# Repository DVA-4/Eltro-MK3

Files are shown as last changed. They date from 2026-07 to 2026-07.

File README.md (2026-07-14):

# Eltro MK3

A Eurorack effects module: a digital emulation of the **Eltro Tempophon** —
the rotating-head tape pitch/time changer famously used to create HAL 9000's
voice in *2001*.

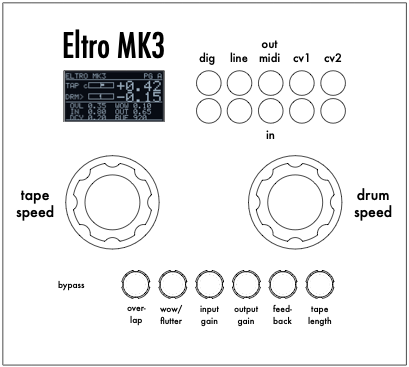
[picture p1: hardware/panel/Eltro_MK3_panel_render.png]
Eltro MK3 panel

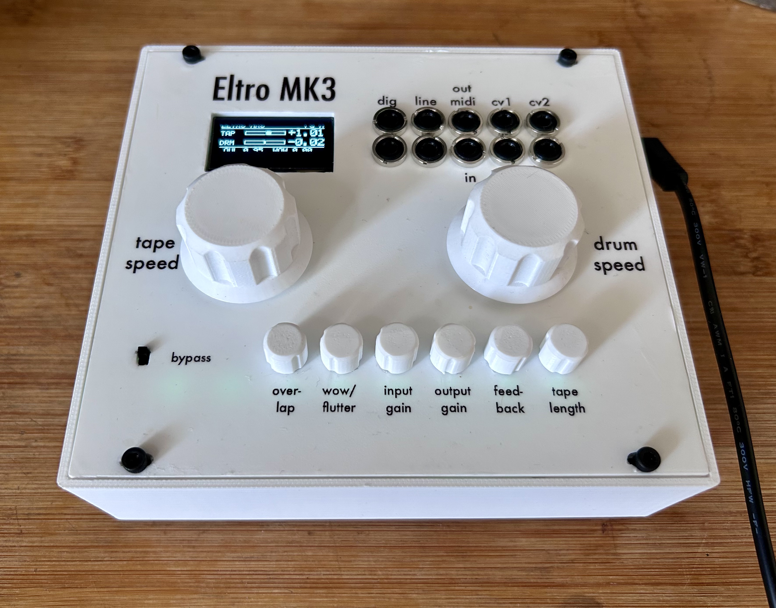
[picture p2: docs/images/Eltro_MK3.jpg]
Eltro MK3 overview

(https://www.youtube.com/watch?v=IvSktSFwxQE)

Live audio in → a buffered "tape" scanned by four virtual read heads → audio
out, with **time and pitch decoupled into two independent axes** (tape and
drum) — the same trick the real machine used, modelled directly rather than
approximated with a generic granular time-stretch.

Built on the **AMYboard** (ESP32-S3) using the **AMY** synth library, with an
M5Stack 8Angle for control, an SH1106 OLED for display, CV inputs, and MIDI
RX/TX.

## Features
- Two-axis DSP: progression (time) and pitch as independent parameters
- Silence-at-freeze, reverse-scan, and speed/pitch decoupling — all modelled
  from the physical machine's behaviour, not faked
- 2× CV inputs (tape, drum)
- MIDI RX (CC control with per-knob pickup/catch takeover) and MIDI TX
  (knob movement → CC out)
- OLED UI with two parameter pages, persisted settings
- 3D-printed Eurorack panel and matching knobs

## Status
Working, hardware-confirmed final prototype. See `CHANGELOG.md` for version
history.

## Repository structure
```
firmware/       Arduino sketch (eltro_mk3_v12) + font table
hardware/       3D-printable panel, knob, and case STLs, panel design source
docs/           Build guide, BOM, user manual, technical notes
```

The skiff case is a remix of a third-party CC BY 4.0 design — see
`hardware/CASE_NOTE.md` for attribution.

## Getting started
- **Building one yourself:** start with `docs/BUILD_GUIDE.md` and `docs/BOM.md`
- **How it works technically:** `docs/TECHNICAL_NOTES.md`
- **How to use it once it's built:** `docs/manual/Eltro_MK3_Manual.pdf`

## Dependencies
- [AMY](https://github.com/shorepine/amy) synth library (MIT licensed) —
  not bundled here, install separately

## License
- Firmware (`firmware/`): MIT — see `LICENSE-CODE.md`
- Hardware designs and documentation (`hardware/`, `docs/`): CC BY-SA 4.0 —
  see `LICENSE-HARDWARE.md`

## Credits
Built by Fabian Rieber 2026 (DVA-4). Digital emulation of the Eltro Tempophon concept;
"itty-bitty bits, cross-faded" description of the segment-crossfade
mechanism is Wendy Carlos's, describing the original hardware.

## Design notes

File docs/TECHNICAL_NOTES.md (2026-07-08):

# Eltro MK3 — Technical Notes

A digital emulation of the **Eltro Tempophon** (the rotating-head tape
pitch/time changer famously used to create HAL 9000's voice in *2001*). Live
audio in → ring buffer ("tape") with four Hann-windowed virtual read heads →
audio out, decoupled into independent time and pitch axes.

The machine is modelled as **two independent axes** — progression (time)
driven by the tape transport, and pitch driven by the relative (tape − drum)
velocity — so time and pitch can be changed independently, the way the real
machine does. Built as an Arduino sketch for the **AMYboard** (ESP32-S3
Eurorack module) using the **AMY** synth library.

---

## Hardware

| Part | Role | I2C addr | Bus |
|---|---|---|-----|
| AMYboard (ESP32-S3) | host + audio I/O | — | — |
| M5Stack 8Angle | 8 pots + toggle + 9 RGB LEDs | `0x43` | front Grove |
| SH1106 128×64 OLED | display | `0x3C` | front Grove |
| ADS1115 | 2× CV input (ADC) | `0x48` | onboard AMYboard — not an external peripheral |

- **Front-panel Grove I2C: SDA = GPIO 17, SCL = GPIO 18** (not 21/22 — that's
  bare-DevKit only; accessories go on the FRONT panel, not the back "host" port).
- **MIDI IN (TRS): GPIO 21** (`AMYBOARD_MIDI_IN`), independent of I2C.
- Audio: 44.1 kHz, block size 256, stereo (`AMY_NCHANS = 2`).
- Audio out = **PCM5101 DAC** (analog line out). Audio in / SPDIF = **PCM9211**
  — these are separate chips; the analog-out path does not go through the PCM9211.

### Eurorack panel
- 26HP panel, 3U (131.8 mm × 128.5 mm). Keep controls within the central
  ~110 mm of height to clear the rails/screw slots.
- The 8Angle is 128 mm long — too long to mount vertically; mounted
  horizontally (knobs in a row across the panel width), remove PCB from case.

---

## Audio architecture

**Uses AMY's external-buffer path, not a render hook.** This is the key
lesson for anyone building a real-time audio-in effect on AMYboard:

```c
loop() (core 1, audio only):
    amy_get_input_buffer(buf);        // pull ADC input block (int16 stereo)
    eltroProcessBlock(buf);           // downmix -> effect -> write mono to L+R
    amy_set_external_input_buffer(buf);
    amy_update();                     // render + I2S write; blocks ~1 block
```

- Two oscillators, `AUDIO_EXT0` (pan hard-left) and `AUDIO_EXT1` (pan
  hard-right), set up under one synth, both `amp_coefs[COEF_CONST] = 1.0`.
- Buffer is int16, interleaved stereo (`buf[2n]=L, buf[2n+1]=R`), length
  `AMY_BLOCK_SIZE * AMY_NCHANS`. No fixed-point conversion needed at the
  boundary — AMY's `L2S()` handles it internally.
- Mono effect: downmix `(L+R)/2`, run the Eltro engine, write the result to
  both L and R.
- `amy_update()` belongs in `loop()` here — it blocks on AMY's background fill
  task and paces the loop. This is the opposite of the render-hook model.

**Why not the render hook:** `amy_external_render_hook` + an `AUDIO_IN0`
oscillator produced an amplitude-independent square wave (MSB-only output)
that survived every fix attempted. The external-buffer path (the official
`AMY_custom_dsp` example) is the correct tool for audio-in passthrough/processing.

---

## The Eltro DSP model — two independent axes

The buffer is a **pre-written tape**: a single write head records the live
input at a constant +1.0 (unit density), independent of everything — tape
speed does not touch the write. All the character comes from how the tape is
*read*.

**Two axes, not one velocity:**

1. **Progression (time axis) = tape.** A single shared grab playhead
   (`s_grab`) walks through the buffered tape at the tape rate
   (`s_grab += tapeSpeed` per sample). Depends on tape only — never on drum.
2. **Pitch axis = (tape − drum).** Within each segment, each of the 4 read
   heads scans its material at the relative velocity
   (`scanRate = tape − drum`). This re-pitches the grabbed material without
   changing how fast progression moves through it.

**Reconciliation (the grain mechanism).** A head reads at
`s_segOrigin[h] + s_segScan[h]`. When a head's scan crosses one segment length
(in either direction), it grabs a fresh segment at the current `s_grab` and
resets its scan. Segments repeat or drop to reconcile the two rates; a Hann
crossfade at the segment edges hides the handoff — essentially Wendy Carlos's
description of "throwing out many itty-bitty bits of the recording,
cross-fading the remaining ones together." The four heads stagger by scan
phase within the segment, so at any instant one head is mid-segment while
another hands off, giving continuous output.

The read heads are **phase-locked** to one master scan phase
(`s_masterScan`, advancing at `tape − drum`), with each head's position
derived as `master + (arcLen/NUM_HEADS)*h`. This keeps the four-head stagger
correct by construction at any buffer/segment length — an earlier
implementation with independent per-head accumulators would drift and produce
a stutter when the buffer or segment length changed at runtime.

**Physics this reproduces** (confirmed on hardware):

| Condition | Result |
|---|---|
| tape == drum | silence / freeze — scan frozen |
| tape − drum == 1 | recorded pitch (unity) — scans at write density |
| drum > tape | reverse scan within the grain |
| tape == 0 | freeze on a spot — grab playhead frozen |
| tape fixed, drum varied | progression HOLDS, pitch MOVES (the decoupling) |

Output pitch = input × (tape − drum), independent of progression rate.
Progression through the tape = tape × sample rate, independent of drum.

`tape` is progression/time (rate through the recording). `drum` enters only
via (tape − drum) = pitch — it is a relative velocity, not a "pitch knob" on
its own.

**Why two axes:** a real-time single-pass effect can't time-stretch a live
stream — the decoupling operates over buffered tape (up to ~20 s of recorded
history) rather than future input. The design goal was the closest
approximation of what the hardware Tempophon actually does mechanically,
rather than a textbook granular time-stretch built backward from "preserve
pitch, change duration."

### Segment length and overlap are the tone controls
Segment length is the grain size — how much tape each head scans before
grabbing a fresh segment — absolute in samples, linear, independent of buffer
length: 64 samples (~1.5 ms, buzzy) to 32768 samples (~743 ms, smooth),
default 4096 (~93 ms). Overlap (0.10–0.95, default 0.25) controls crossfade
depth; the grain handoff clicks without enough crossfade, and seams become
audible below ~0.10.

### Speed-knob taper
The tape and drum knobs map through an exponential taper (`out = sign(x) ·
|x|^γ · range`) so the musically dense −1…+1 region around the centre detent
gets more knob travel. Default γ = 2.0. Tunable live over serial and
persisted to flash.

---

## Front-panel LEDs
Computed from `readthru = tape − drum` and `shift = readthru − 1`, using the
effective pitch axis (knob + CV + MIDI), so the ring reflects what's actually
happening rather than just knob position: dim red at silence, green at unity,
blue when faster/up, amber when slower/down. Bypass shows all-red, Page B
shows all-green. A turned knob flashes white briefly over whatever colour is
showing.

---

## Dual-core split (required for continuous audio)
The OLED full-frame flush is ~100 ms of blocking I2C. On a single core this
starves the audio loop. Fix:

- **Core 1 (`loop()`): audio only.** Touches no I2C.
- **Core 0 (`uiTask`):** all I2C — pots, LEDs, OLED flush, MIDI parse. Sole
  owner of the Wire bus, so there's no cross-core I2C race and no mutex needed.
- Shared parameters are `volatile` and word-sized → atomic on ESP32.
- Healthy throughput indicator: ~172 blocks/s (44100/256). Well below that
  means something is blocking the audio loop.

## Setup ordering: `amy_start()` before any Wire/I2C

`amy_start()` configures the PCM9211/PCM5101 codecs over I2C and brings up the
I2S clock/framing from the pristine power-on bus. If any I2C runs first
(`Wire.begin()`, pot reads, LED writes, OLED init), the I2S TX framing latches
wrong on cold power-up — loud, distorted, level-independent analog output,
even though the digital samples are clean. The latch survives warm reset and
reflash (it's codec/I2S clock state, not CPU state) and clears only on a
power cycle or a TX-only I2S init.

**Order:**
1. Before `amy_start()`: USB/CDC + Serial, Serial1 MIDI setup, non-I2C state.
   No Wire.
2. `amy_start(cfg)`.
3. After `amy_start()`: one `Wire.begin()/setClock()` (sole bus bring-up),
   then pots/LEDs, then display init, then oscillator events, then the UI task.

---

## MIDI

**RX:** byte-at-a-time state-machine parser with running-status support
(replacing a naive fixed 3-byte reader, which mis-frames on running status).
Tracks running status, ignores real-time bytes, dispatches only Control
Change. Runs in `uiTask` (core 0), bounded per pass so a CC flood can't
starve the UI.

Fixed CC map (Page A knobs), all 7-bit, RX channel selectable:

| CC | Param | Mapping |
|----|---|---|
| 102 | tape | bipolar taper (same law as the knob) |
| 103 | drum | bipolar taper |
| 104 | overlap | 0.10–0.95 |
| 105 | wow | 0.0–0.05 |
| 106 | input gain | 0.0–4.0 |
| 107 | output gain | 0.0–1.5 |
| 108 | decay | 0.0–0.9999 |
| 109 | buffer length | log 512–884736 |
| 65 | page toggle | ≥64 → Page B |

CCs are chosen from the spec's undefined range (102–119) to avoid colliding
with standard controllers.

**Catch-style takeover (per knob).** An incoming CC sets the parameter and
marks that knob "MIDI-owned"; the physical pot is then ignored for that
parameter until it moves past a raw-ADC threshold. Ownership is per-knob, so
you can automate one parameter over MIDI while tweaking another by hand. The
OLED shows a small marker next to any MIDI-owned Page-A knob.

**TX:** knob-turn → CC out (same CC map as RX), physical-move-only, and
guarded so it never echoes an incoming CC back out (skips any knob currently
MIDI-owned). Deadband is 7-bit re-quantization — emits only when the outgoing
0–127 value changes.

**Electrical note on MIDI-out:** the AMYboard MIDI-out is not a simple
single-pin UART TX — it brings two GPIOs to the two TRS-out contacts. A
DIN-4/5 opto input needs both legs actively defined (it's a current loop), so
MIDI TX is driven **differentially**: UART1 TX normal on one GPIO, its
hardware-inverted mirror on a second GPIO via the ESP32-S3 GPIO matrix. A
single-ended drive (TX pin + a floating or static-LOW return) produced
silence or garbled data into test interfaces. This is a clever way the board
delivers a 5V-era MIDI signal cleanly from 3.3V logic; it is not a
single-ended-plus-ground design.

---

## CV inputs
Two CV inputs are read from an ADS1115 (I2C `0x48`, single-ended A0/A1) in
`uiTask`, alternating (ping-pong) single-shot conversion at ~50 Hz, lightly
smoothed, mapped 1 unit/volt and clamped to ±5.0. CV1 → tape, CV2 → drum,
both additive (`effectiveTape = tape + cv·scale + offset`), with per-channel
scale/offset available in the parameter pages. Unpatched inputs float at a
nonzero reading, so CV amount should be kept at 0 until a cable is patched.

---

## Toolchain

**Known-good pairing:** arduino-esp32 core 3.3.8+ together with AMY library
1.2.14+ (or `main`). The AMYboard board target itself only exists from core
3.3.x onward, so you cannot go below 3.3.8 and still select the AMYboard
board.

**A version-skew failure mode worth knowing about:** if the board package is
updated but the AMY library is left on an older release, synth-out (I2S TX
only) still works cleanly, but audio-in → out (full-duplex RX+TX) produces
loud, very distorted, level-independent garbage — even though the digital
samples in the buffer are provably clean. This looks like a code regression
but isn't; the fix is updating AMY to match the core, not rolling the core
back.

If you move to a newer core, update AMY in lockstep and re-validate the
audio-in path with a minimal passthrough sketch before assuming a full
instrument sketch is at fault.

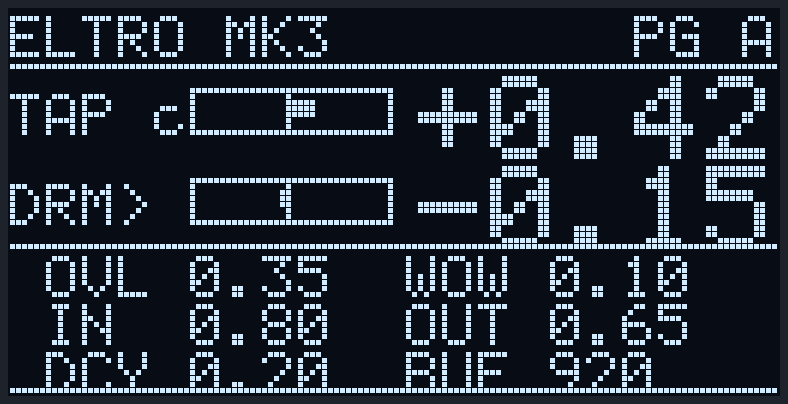
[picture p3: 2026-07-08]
docs/images/eltro_oled_pageA.png

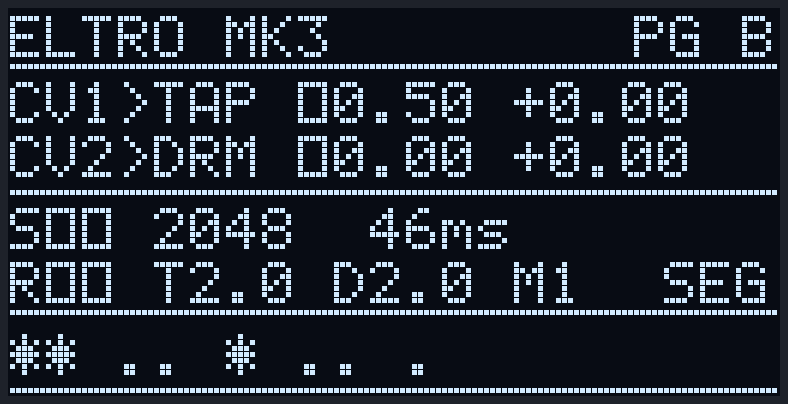
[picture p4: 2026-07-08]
docs/images/eltro_oled_pageB.png

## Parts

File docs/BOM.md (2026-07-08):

# Bill of Materials

Parts confirmed from the firmware and technical notes. Fill in exact sources,
part numbers, and prices where you'd like to point builders to what you
actually used.

| Part | Role | Notes | Source / link |
|---|---|---|---|
| AMYboard (ESP32-S3) | Main host, audio I/O | Eurorack-format synth/DSP board running the AMY library. Includes the ADS1115 CV-input ADC onboard — not a separate part | |
| M5Stack 8Angle | 8 potentiometers + toggle + 9 RGB LEDs | I2C `0x43`, connects to AMYboard's **front-panel** Grove I2C (not the back host port) | |
| SH1106 128×64 OLED | Display | I2C `0x3C`, same Grove bus as the 8Angle, you need to solder a Y-cable for the four I2c pins | |
| Eurorack panel (3D printed) | Front panel, 26HP / 3U — two variants, see `hardware/panel/` | `Eltro_MK3_Panel_Stock8Angle.stl` (unmodified 8Angle PCB) or `Eltro_MK3_Panel_ExternalPots.stl` (two pots broken out externally — what this build uses) | printed by you |
| Knobs (3D printed, ×2 designs) | Big/small knobs for the 8Angle pots | See `hardware/knobs/` | printed by you |
| 3U/28HP skiff case (3D printed) | Enclosure | Remix of a CC BY 4.0 MakerWorld design — see `hardware/CASE_NOTE.md` | printed by you |
| Jacks, cables, mounting hardware | Audio I/O, CV I/O, MIDI, panel mounting | | |

** all files 3D printed on a Bambulab P2S with PETG filament, no supports, 0,4mm nozzle**

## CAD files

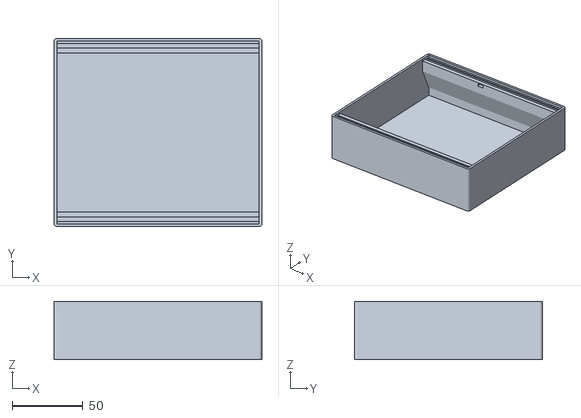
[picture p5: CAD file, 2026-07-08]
hardware/case/EURORACK_SKIFF_3U_28HP_41mm_height.stl
146.9 x 133.0 x 41.0

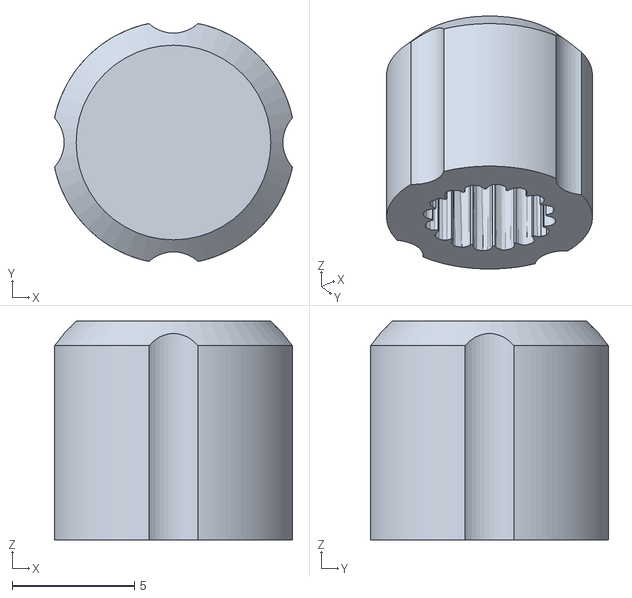
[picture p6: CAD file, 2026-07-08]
hardware/knobs/Eltro_MK3_small_knob.stl
9.74 x 9.74 x 8.95

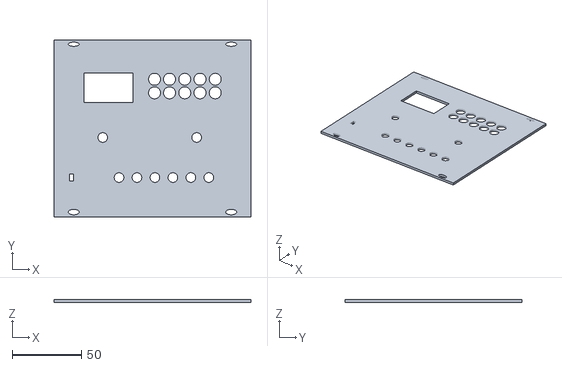
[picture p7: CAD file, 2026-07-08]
hardware/panel/Eltro_MK3_Panel_ExternalPots.stl
142.6 x 128.0 x 2.00

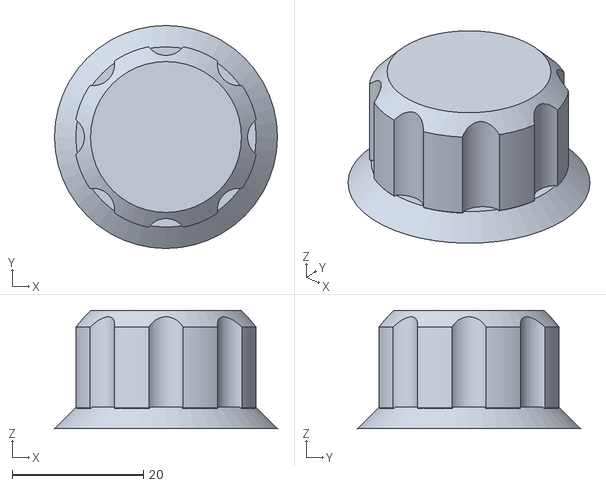
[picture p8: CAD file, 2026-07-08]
hardware/knobs/Eltro_MK3_big_knob.stl
34.0 x 34.0 x 18.0

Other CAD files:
hardware/panel/Eltro_MK3_Panel_Stock8Angle.stl

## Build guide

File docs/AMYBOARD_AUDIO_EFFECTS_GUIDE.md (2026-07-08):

# Building Audio Effects on the AMYboard — Practical Guide

Patterns and hard-won lessons for **real-time audio in -> process -> out**
effects on the **AMYboard** (ESP32-S3 + AMY library), with an **8Angle** for
control and an **OLED** for display. Generalised from the Eltro MK II build.

---

## 1. The audio path: use the external-buffer API

For any "process live audio" effect, use AMY's **external-buffer** path. Do NOT
use a render hook for audio-in passthrough/processing.

```c
// setup(): enable audio in, define two AUDIO_EXT oscillators (stereo)
amy_config_t cfg = amy_default_config();
cfg.features.audio_in = 1;
amy_start(cfg);

amy_event e = amy_default_event();
e.reset_osc = RESET_AMY; amy_add_event(&e);

e = amy_default_event();
e.synth = 18; e.num_voices = 1; e.oscs_per_voice = 2; amy_add_event(&e);

// osc 0 = left, osc 1 = right
e = amy_default_event(); e.synth=18; e.osc=0; e.wave=AUDIO_EXT0;
e.pan_coefs[COEF_CONST]=0.0f; e.amp_coefs[COEF_CONST]=1.0f; e.velocity=1.0f;
amy_add_event(&e);
e = amy_default_event(); e.synth=18; e.osc=1; e.wave=AUDIO_EXT1;
e.pan_coefs[COEF_CONST]=1.0f; e.amp_coefs[COEF_CONST]=1.0f; e.velocity=1.0f;
amy_add_event(&e);
// then note-on both EXT oscs to activate them.
```

```c
// loop() = AUDIO ONLY:
amy_get_input_buffer(buf);          // int16 stereo interleaved, BLOCK_SIZE*NCHANS
processBlock(buf);                  // your DSP, in place
amy_set_external_input_buffer(buf);
amy_update();                       // blocks ~1 block; paces the loop
```

### Buffer format
- `output_sample_type` = **int16**, **interleaved stereo**: `buf[2n]=L`,
  `buf[2n+1]=R`. Length = `AMY_BLOCK_SIZE * AMY_NCHANS`.
- Work in plain int16 (or convert to float ±32768 and back). **Do NOT do AMY
  s8.23 fixed-point (F2S) at this boundary** — AMY handles that internally via
  `L2S()`. Manual F2S here is how you get silence or square-wave garbage.
- Mono effect on stereo I/O: downmix `(L+R)/2`, process once, write result to
  both L and R.

### Why not the render hook
`amy_external_render_hook` + an `AUDIO_IN0` oscillator is the "obvious" approach
and it is a trap for audio-in effects. It forces you into per-osc s8.23 buffers,
pan/amp coef gymnastics, and (empirically) produced an **amplitude-independent
square wave** that no amount of scaling fixed. The external-buffer path is the
official, working pattern (`AMY_custom_dsp` example). Reach for it first.

---

## 2. Dual-core is mandatory if you have an OLED

A full-frame SH1106/SSD1306 flush over 100 kHz I2C takes **~100 ms** (blocking).
If the audio loop and the display live on the same core, the flush starves audio
and you get periodic dropouts (~10-20 per second). The audio block rate at
44.1k/256 is **~172 blocks/s**; watch that number — if it falls well below 172,
something is blocking your audio loop.

**Split across the two cores:**
- **Core 1 (`loop()`):** audio pump only. Touches NO I2C.
- **Core 0 (`xTaskCreatePinnedToCore(uiTask, "ui", 8192, NULL, 1, NULL, 0)`):**
  all I2C — pots, LEDs, OLED, MIDI parse + MIDI send.

### I2C ownership rule (avoids the nastiest bug class)
Make **one task the sole owner of the Wire bus.** When the audio core touches no
I2C and the UI task owns it exclusively, there is **no cross-core I2C race and no
mutex needed.** Cross-core I2C contention on a shared bus is a brutal,
intermittent bug — design it out by ownership, not by locking.

### Init ordering: `amy_start()` before any Wire/I2C
Separate from the runtime ownership rule above: at startup, `amy_start()` must run
**before** the first `Wire.begin()` or any I2C traffic. `amy_start()` configures
the codecs over I2C and brings up I2S framing from the pristine power-on bus;
touching I2C first latches the I2S **TX** framing wrong on **cold boot** (loud,
distorted, level-independent analog out, but clean digital samples — and it
survives reset/reflash, clearing only on a power cycle). Do non-I2C setup +
`amy_start()` first, then bring up Wire and all peripherals. The official example
cold-boots clean precisely because it touches no I2C before `amy_start()`.

### Sharing state between cores
DSP params written by the UI task and read by the audio task: declare `volatile`
and keep them **word-sized** (float, int, bool). Those reads/writes are atomic on
ESP32 — no mutex. Don't share multi-word structs without protection.

---

## 3. Control surface (8Angle)

| Function | I2C (addr `0x43`) |
|---|---|
| Read pot ch (0-7) | write reg `ch*2`, read 2 bytes LE (12-bit, 0-4095) |
| Read toggle | write reg `0x20`, read 1 byte, bit 0 |
| Set RGB LED ch | write reg `0x30 + ch*4`, then R, G, B, brightness |

### Orientation: keep TWO separate concepts
- **Channel order** (which physical knob is logical N): flips if you mount the
  board rotated. Remap logical->hardware at BOTH the pot read AND the LED write
  so everything downstream (params, LEDs, labels) stays consistent.
- **Turn direction** (CW increases vs decreases): **electrical, independent of
  mounting.** Rotating the board does NOT change a pot's CW sense. Use a separate
  invert flag (`v = 4095 - v`). Do not tie direction to the mounting flag.

### Pot smoothing / deadband
Use a deadband (e.g. ignore changes < ~20 LSB) before treating a pot as "moved",
to avoid jitter and to drive "last touched knob" display logic. The same
"moved?" gate is what MIDI TX hangs off of (send a CC only on real movement).

---

## 4. Display (OLED)

- Lives on the UI core (it's the ~100 ms blocker — keep it off audio).
- 10 fps (`DISPLAY_MS = 100`) is plenty for knob feedback and cheap.
- Watch horizontal overflow: a 128px-wide SH1106 at a 6px font fits **~21
  chars/row**. Strings longer than that silently clip off the right edge — a
  value can be "in the code" but invisible. Budget pixels per row.
- Prefer gauges over redundant numbers when space is tight; show the precise/most
  musical value (e.g. pitch in cents) once, prominently.

---

## 5. Gain staging

AMYboard analog audio-in is **quiet**. Either bump the EXT oscillator amp
(`amp_coefs[COEF_CONST]`, the official example uses ~5.0) OR provide an input-gain
control in your effect (cleaner — keeps the osc at unity and avoids surprise
loudness). Provide an output gain too. Watch for clipping when feedback/decay
effects accumulate energy.

---

## 6. Debugging methodology (this saved the project)

- **Build markers.** Print `Ready [BUILD: rev-X]` on boot. ALWAYS confirm the
  marker on-device matches the file you flashed. Editor/flash desync wastes hours
  of "fixes that did nothing because they weren't running."
- **Measure, don't assume.** Print raw sample values; scope the actual analog
  out. An "envelope that matches" is not proof the waveform is intact. We chased
  several wrong theories that a single raw-sample dump or scope trace killed
  instantly. (The MIDI-out fix was pure scope work: pin → jack → DIN pins.)
- **Isolate with minimal sketches.** A bare "AMY plays one sine" sketch and a
  bare "native audio-in passthrough" sketch partitioned the problem (DAC path vs
  input path vs our code) far faster than reasoning about the full sketch. A tiny
  standalone "spam a CC out" sketch did the same for MIDI TX.
- **Amplitude sweep test.** If output looks wrong, drive the input at 0.8 / 0.1 /
  0.01 and scope it. **Same shape at all three = sign/format/MSB bug**
  (amplitude-independent). **Scales with input = gain/clipping.** These need
  opposite fixes; the sweep tells you which instantly.
- **Treat disproven theories as real signal.** Each "that didn't fix it" narrows
  the space — don't re-pursue a killed hypothesis without new evidence.

- **When mutating-toward-broken stalls, bisect from the GOOD side.** If poking at
  your broken sketch keeps hitting confounds, start from a *known-good minimal
  example* and inject your sketch's differences into it ONE at a time until it
  breaks. The injection that flips it is the cause, isolated from everything else.
  This is what finally cracked the cold-boot latch: AMY's bare example cold-booted
  clean, so we added Eltro's `setup()` deltas to it cumulatively (midi config →
  manual USB → pre-`amy_start` I2C) and the break tracked exactly to I2C-before-
  `amy_start()`. Mutating the other direction had buried it under OLED-freeze and
  version-skew noise for a whole prior session.

- **A clean digital dump with garbage analog points at the I2S/clock layer, not
  your DSP.** If `out16` (or your equivalent sample dump) is a perfect waveform
  while the analog out is mangled, stop auditing your code — the corruption is in
  I2S framing / codec clocking. RX-data bugs show up *in* the dump; TX-framing
  bugs don't. (Same logic for MIDI: garbled-arriving vs nothing-arriving point at
  different layers — see the programming guide's MIDI-out section.)

---

## 7. Quick reference

- Front Grove I2C: **SDA 17, SCL 18** (not 21/22).
- MIDI IN: **GPIO 21**, 31250 baud, RX only. Input is polarity-agnostic
  (bridge rectifier ahead of the opto — accepts TRS Type-A or B).
- MIDI OUT: **differential** — UART1 TX normal on **GPIO 14**, inverted mirror on
  **GPIO 15** via the GPIO matrix. NOT single-ended. See the programming guide.
- Audio: 44.1 kHz, block 256, stereo, `AMY_NCHANS = 2`.
- Output DAC: PCM5101 (analog). Input/SPDIF: PCM9211. Separate chips.
- Healthy audio loop: **~172 blocks/s**.

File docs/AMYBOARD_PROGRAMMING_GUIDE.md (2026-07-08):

# Programming the AMYboard — General Guide

Foundational notes for building anything on the **AMYboard** (ESP32-S3 + AMY
synth library) in the Arduino environment, with I2C peripherals (8Angle, OLED,
ADCs, ...) and notes on real-time MIDI. Distilled from the Eltro MK II project so
future builds don't relearn it the hard way.

---

## 1. Board basics

- MCU: **ESP32-S3** (dual core, PSRAM). Arduino board target **AMYboard** sets
  `-DAMYBOARD_ARDUINO` and `cdc_on_boot=0`.
- **`AMYBOARD_ARDUINO` vs `AMYBOARD` are NOT the same define.** The Arduino target
  defines `AMYBOARD_ARDUINO` only. Library code gated on plain `defined(AMYBOARD)`
  (some MIDI/parser paths) is silently EXCLUDED on Arduino builds. If something in
  AMY "should be there" but isn't compiling in, check which of the two defines
  gates it.
- **USB CDC**: with `cdc_on_boot=0`, set up USB-CDC manually:
  ```c
  #if !ARDUINO_USB_CDC_ON_BOOT
  #include "USB.h"
  USBCDC USBSerial;
  #define Serial USBSerial
  #endif
  // in setup(): USB.begin(); Serial.begin(115200);
  ```
- **Do not enable AMY's USB-MIDI** (`cfg.midi = AMY_MIDI_IS_NONE`) when you run
  your own manual USB-CDC — the USB gadget descriptors conflict and can hang boot.

### Pin map that actually matters
| Signal | Pin | Notes |
|---|-----|---|
| Front Grove I2C SDA | **GPIO 17** | accessories go here, NOT 21/22 |
| Front Grove I2C SCL | **GPIO 18** | (21/22 is bare-DevKit only) |
| MIDI IN (TRS) | **GPIO 21** | `AMYBOARD_MIDI_IN`, independent of I2C |
| MIDI OUT contact A | **GPIO 14** | `AMYBOARD_MIDI_OUT_TYPE_A`, → tip → DIN pin 5 |
| MIDI OUT contact B | **GPIO 15** | `AMYBOARD_MIDI_OUT_TYPE_B`, → ring → DIN pin 4 |
| I2S (audio) | internal | handled by AMY; don't touch |

- MIDI OUT is **two GPIOs, one per TRS contact, each via a 22 Ω series resistor**
  — it is a differential/current-loop output, not a single-ended TX pin. See §5.
- Audio chips: **PCM5101** = analog line OUT (DAC, no I2C, config-free).
  **PCM9211** = analog/SPDIF IN + SPDIF out (I2C `0x40`). **ADS1015** = CV ADC
  (I2C). These are distinct — the analog-out path does not pass through the
  PCM9211.

---

## 2. AMY startup skeleton

```c
amy_config_t cfg = amy_default_config();
cfg.features.startup_bleep  = 0;
cfg.features.default_synths = 0;
cfg.features.chorus = 0; cfg.features.reverb = 0;   // disable what you don't use
cfg.features.audio_in = 1;                          // if you need input
cfg.midi = AMY_MIDI_IS_NONE;                        // if doing your own MIDI/USB
amy_start(cfg);
```

- Defaults: 44.1 kHz, block size 256, `AMY_NCHANS = 2`, `multithread = 1`.
- With `multithread = 1`, AMY runs a **background fill task**; `amy_update()`
  **blocks** on it (`ulTaskNotifyTake(portMAX_DELAY)`). That blocking is the
  intended pacing mechanism when you drive audio from `loop()`.
- Whether you call `amy_update()` in loop depends on your model:
  - **External-buffer / audio-in effects:** YES — it pulls your buffer and paces
    the loop (see the audio-effects guide).
  - **Pure synth with no per-loop buffer work:** AMY's background task already
    drives audio; an extra `amy_update()` may just block. Match the official
    example for your use case.

### ⚠️ Call `amy_start()` BEFORE any Wire/I2C (codec bring-up ordering)

`amy_start()` configures the PCM9211/PCM5101 over I2C and brings up I2S
clock/framing from the **pristine power-on bus**. If you touch I2C first
(`Wire.begin()`, peripheral reads, OLED init), the I2S **TX** framing can latch
wrong on **cold power-up**: loud, distorted, level-independent analog out with
*clean digital samples*. It survives reset/reflash (codec/I2S clock state, not
CPU state) and clears only on a power cycle or a TX-only init — so it looks like
black magic. Rule: do all non-I2C setup + `amy_start()` first, then `Wire.begin()`
and every I2C peripheral after. The official `AMY_custom_dsp` example follows this
(it touches no I2C before `amy_start()`), which is why it cold-boots clean.

---

## 3. The dual-core pattern (use it whenever you have slow I2C + audio)

ESP32-S3 has two cores. Slow blocking work (OLED flush ~100 ms, big I2C bursts)
must NOT share a core with the audio loop.

```c
void uiTask(void* arg) {
    for (;;) {
        // pots, LEDs, OLED flush, MIDI parse+send — ALL I2C lives here
        vTaskDelay(pdMS_TO_TICKS(2));   // feed watchdog / bound the rate
    }
}
// setup():
xTaskCreatePinnedToCore(uiTask, "ui", 8192, NULL, 1, NULL, 0);  // core 0
// loop() (core 1) = audio / time-critical only, touches NO I2C
```

**Rules that prevent the worst bugs:**
1. **One task owns the I2C bus.** Never touch Wire from both cores. With a single
   owner you need no mutex and you avoid intermittent bus-wedge races.
2. **Shared state = `volatile` + word-sized** (float/int/bool) -> atomic on
   ESP32, no mutex. Multi-word structs need protection; avoid sharing them.
3. **Serial from one core ideally.** Two cores doing `Serial.printf` can interleave
   /garble. If you must, keep it rare and short.
4. **MIDI TX belongs on the UI core too** — emit CCs from the same task that reads
   the pots, so the read → compare → send path is single-threaded and never races
   the values it's transmitting.

---

## 4. I2C peripheral cookbook

Generic register-style I2C device (8Angle, ADS1015, OLED all follow this shape):

```c
// write register pointer, read N bytes:
Wire.beginTransmission(ADDR);
Wire.write(reg);
Wire.endTransmission(false);          // repeated-start; keep bus for the read
Wire.requestFrom(ADDR, N);
while (Wire.available()) { ... }
```

- **M5Stack 8Angle (`0x43`):** pot ch -> reg `ch*2`, 2 bytes LE, 12-bit. Toggle
  -> reg `0x20` bit0. LED -> reg `0x30+ch*4` then R,G,B,bright.
- **SH1106/SSD1306 OLED (`0x3C`):** command stream prefix `0x00`, data stream
  prefix `0x40`. Chunk data (Arduino Wire TX buffer is small — write ~16 data
  bytes per transaction). Full 128x64 flush ~100 ms at 100 kHz -> keep on UI core.
- **ADS1015/1115 (CV ADC):** config register sets mux/gain/rate; conversion
  register holds the result. Good for reading CV/control voltages.

### Orientation flags for rotary controls (generalises beyond 8Angle)
Keep **channel order** (which knob is which) and **turn direction** (CW up vs
down) as **two independent flags**. Mounting the board rotated changes the
former, never the latter. Direction is electrical: `v = MAX - v`.

### I2C bus speed
Default 100 kHz is conservative (chosen for the slowest device, e.g. the 8Angle's
STM32). Bumping to 400 kHz (`Wire.setClock(400000)`) cuts a ~100 ms OLED flush to
~25 ms if every device on the bus tolerates it — verify each datasheet first.

---

## 5. Real-time MIDI (read this before you "just add" it)

A basic MIDI-IN UART is easy; **real-time/clock-tight MIDI is not.** Know which
you're building.

### Basic MIDI IN (works, low effort)
```c
Serial1.begin(31250, SERIAL_8N1, AMYBOARD_MIDI_IN, -1);  // RX only
// in uiTask: read 3-byte channel messages, dispatch CCs/notes
```
- 31250 baud, GPIO 21, the physical layer is the fiddly part — but once a single
  CC gets through, your wiring/polarity is proven. Adding more CCs is then just
  more `if (cc == X)` cases.
- **MIDI IN physical layer is polarity-agnostic on this board.** The input has a
  **bridge rectifier ahead of the H11L1 optocoupler**, so it accepts either TRS
  Type-A or Type-B without a jumper — don't burn time chasing input polarity.
- **Resolution caveat:** CC value is 7-bit (0-127). Mapping to a wide parameter
  range is coarse (128 steps). Use 14-bit (CC MSB+LSB) or pitch-bend for smooth.

### MIDI OUT on the AMYboard — the differential-drive gotcha (this is the big one)

MIDI OUT is **NOT a single-pin UART TX** on this board. It routes two GPIOs to the
two TRS out contacts, each through a 22 Ω series resistor:
`AMYBOARD_MIDI_OUT_TYPE_A = 14` (→ tip → DIN pin 5) and
`AMYBOARD_MIDI_OUT_TYPE_B = 15` (→ ring → DIN pin 4). A standard DIN MIDI input is
a **current loop** (pins 4–5) and needs BOTH legs actively defined.

**Measured truth table** (sending CC into a MOTU M2 — a deliberately picky
receiver; if it's clean there it's clean anywhere):

| TX pin | Other pin | Result |
|---|---|---|
| 14 | 15 floating | silence (return leg undefined) |
| 14 | 15 driven LOW | silence |
| 15 | 14 floating | silence |
| 15 | 14 driven LOW | **garbled** (loop closes, but static-LOW return is marginal → dirty edges → receiver mis-frames status bytes) |

A static-LOW return *closes* the loop but drives it so marginally (3.3 V, 22 Ω,
single-ended) that a picky opto input mis-samples bit edges — the monitor shows
scattered Program/Note/PitchWheel messages on random channels while the ramping
value byte leaks through recognizably. Do not ship this.

**Correct fix — differential push-pull drive.** Drive UART1 TX **normal on GPIO 14**
and its **hardware-inverted mirror on GPIO 15** via the ESP32-S3 GPIO matrix:

```c
#include "esp_rom_gpio.h"
#include "soc/uart_periph.h"
#include "hal/gpio_hal.h"

Serial1.begin(31250, SERIAL_8N1, AMYBOARD_MIDI_IN, 14);  // TX normal on 14
Serial1.setPins(AMYBOARD_MIDI_IN, 14);
uint32_t tx_sig = uart_periph_signal[1].pins[SOC_UART_TX_PIN_IDX].signal; // UART1
gpio_set_direction((gpio_num_t)15, GPIO_MODE_OUTPUT);
esp_rom_gpio_connect_out_signal((gpio_num_t)15, tx_sig, true /*invert*/, false);
```

The opto then sees a full push-pull differential swing with clean, bit-aligned
edges (both pads emit the same UART1 TX signal in hardware, one inverted, zero
CPU, no skew). **Orientation matters: TX on 14, inverted mirror on 15 — the
reverse garbles.** This is how the board drives a 5 V-era MIDI input cleanly from
3.3 V logic (differential ≈ 2× headroom).

**Why AMY's own code doesn't reveal this:** AMY's `esp_init_midi` does a plain
single-ended `uart_set_pin(uart, midi_out, midi_in, ...)` on ONE pin, and nothing
in the tree ever drives the second contact. Single-ended is fine for a **TRS-native
Type-A receiver** (the return is defined by the TRS standard), but NOT for a
**DIN-4/5 loop via a TRS→DIN adapter**, which is why you must drive the return
actively yourself. Selecting Type-A vs Type-B in AMY just changes *which* single
pin carries data; it never sets up the differential drive.

**Debug path that cracked it (generalises):** scope the ESP pin (does TX leave the
chip?), then the jack (does the board pass it?), then the DIN pins (did data reach
pin 4/5, and on which contact?). This walks the signal outward and localizes the
fault to a *layer* — here, the loop's return leg — instead of guessing. The `.ino`
code was correct the whole time; the fault was purely the output electrical layer.

### MIDI TX logic (knob → CC), once the electrical layer works
- **Physical-move-only, never echo RX.** Send only inside the pot
  `any_changed`/deadband path, and skip any parameter currently driven by an
  incoming CC (`s_midiOwned[]`) so RX→TX can't feedback-loop.
- **Deadband = 7-bit re-quantization.** Emit only when the outgoing 0–127 value
  actually changes; a caught pot resting under a finger then never spews CCs.
- **Prime a baseline.** On the first pass capture current positions and send
  nothing, so touching one knob doesn't blast all eight.
- **Send raw knob position** (e.g. `pot_raw>>5`) if RX applies the same taper on
  the way back in — that makes a DAW round-trip a knob to the same sound.

### Why a basic parser is NOT clock-ready
1. **Timing/jitter, not parsing, is the problem.** If MIDI is serviced in the UI
   task that also runs the ~100 ms OLED flush, bytes queue during the flush and
   get processed in a burst afterwards -> up to ~100 ms of jitter. MIDI clock
   (24 PPQN, one byte every ~20 ms at 120 BPM) becomes lurching/unusable.
2. **Real-time messages are single bytes** (clock `0xF8`, start/stop/continue)
   that can appear ANYWHERE, even mid-message. A fixed "wait for 3 bytes" parser
   mis-frames on them.

### Doing clock properly (when you commit to it)
- **Timestamp `0xF8` as close to the wire as possible** — UART ISR / driver event
  queue, NOT in a task that can be blocked by the OLED. This is the single biggest
  lever against jitter.
- **Byte-at-a-time state-machine parser** with running-status support that
  dispatches single-byte real-time messages immediately, separate from channel-
  message assembly.
- **Tempo recovery is inherently noisy** (24 PPQN is a coarse estimate). Everyone
  picks a different smoothing filter (PLL / moving average); that's WHY device A
  syncs tight to B but wobbles with C. Choose your tempo-filter tradeoff
  consciously; don't inherit it by accident.
- **No phase reference in clock alone** — use Start/Continue for the downbeat
  anchor.

Bottom line: occasional set-once CCs are a trivial add to a basic parser;
real-time clock is a deliberate feature needing its own ISR-timestamped,
state-machine architecture. Don't bolt clock onto a display-blocked task.

---

## 6. Debugging methodology (project-agnostic, earned the hard way)

- **Build markers.** Print `Ready [BUILD: rev-X]` on boot; confirm on-device that
  the running binary matches the edited file. Tooling/flash desync silently
  invalidates "fixes."
- **Measure, never assume.** Dump raw values; scope real outputs. A matching
  envelope is not a matching waveform. (The MIDI-out fix came from scoping the
  pin → jack → DIN pins, not from re-reading the code.)
- **Walk the signal outward to localize a fault to a layer.** For any output
  chain (MIDI, audio, CV), probe at successive physical points — chip pin, board
  connector, cable far end — and the first point where it breaks names the
  culprit layer. Saves you auditing correct code.
- **Isolate with minimal sketches** to partition a problem (is it the DAC path,
  the input path, or my code?). One bare sketch beats hours of reasoning about a
  big one. (A ~40-line heartbeat sketch that just spammed a CC out is what let us
  build the MIDI-out truth table cleanly, away from the full firmware.)
- **Amplitude sweep** for "output looks wrong": drive 0.8/0.1/0.01.
  Same shape = sign/format/MSB bug; scales = gain/clip. Opposite fixes.
- **Read a garbled-vs-silent distinction as a real clue.** *Nothing* arriving =
  the physical loop isn't conducting (open leg, wrong pin). *Garbage* arriving =
  bytes conduct but edges/levels are marginal (mis-sampling). They point at
  different layers and different fixes.
- **Trust source over inference for this board.** Repeatedly, reasoning from the
  schematic or the MIDI spec pointed the wrong way (input "polarity", which pin is
  "Type-A", single-vs-differential); the AMY source and direct measurement settled
  each one. When they disagree, believe the measurement.
- **Disproven theories are progress** — they shrink the search space. Don't loop
  back to a killed hypothesis without new evidence.
- **Single-owner discipline** for shared resources (I2C bus, Serial) prevents the
  hardest-to-reproduce class of bugs.

---

## 9. Toolchain version pinning (do not skip)

AMY's I2S layer is **tightly coupled to the arduino-esp32 core / ESP-IDF
version.** AMY's maintainers actively patch `src/i2s.c` to track board-package
changes, which means a board update can require a matching AMY update — and a
mismatch breaks audio subtly.

**Pin the known-good pairing and record it in your project:**
- AMY documents its tested combo in `docs/arduino.md` (e.g. "arduino-esp32
  3.2.0"). Use that core version with the matching AMY release.
- Updating arduino-esp32 to a newer core without updating AMY can break the
  **full-duplex audio-in (I2S RX)** path while leaving **synth-out (I2S TX)**
  working — a confusing, misleading failure that looks like a code regression.

**Diagnostic signature of a core/AMY version skew:**
- Bare "AMY plays a sine" sketch: clean (TX works).
- Audio in -> out: loud/distorted/level-independent (RX path broken).
- Your code unchanged, build marker correct, digital output samples clean.

**Fix:** roll the core back to the AMY-tested version (Boards Manager -> esp32 ->
version dropdown), OR update AMY in lockstep to a release that supports the newer
core. Change ONE thing at a time and re-validate audio-in with a minimal
passthrough before touching your sketch. The sketch is almost never the cause of
this particular failure.

**⚠️ Same symptom, different cause — disambiguate first.** "Loud/distorted/
level-independent audio-in with clean digital samples" has (at least) TWO root
causes:
- **Version skew (this section):** the *bare* audio-in passthrough example also
  breaks; independent of init order; fixed by aligning (core, AMY) versions.
- **I2C-before-`amy_start()` (a setup-ordering bug):** the bare example **works**;
  only your sketch breaks; survives reflash/reset but a power cycle re-breaks it;
  fixed by calling `amy_start()` before any Wire/I2C (see the startup section).
Decisive test: flash the bare official example and power-cycle it. Clean → it's
your init order, not versions. Broken → versions.

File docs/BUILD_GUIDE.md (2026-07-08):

# Build Guide

You only need  the Amyboard, M5stack 8-angle 8-pot peripheral and any SH1106 I2C OLED and a Y-cable for connecting both OLED and 8-angle unit to the Amyboard to get you started.
There ist two versions of the Eurorack frontpanel. One uses the stock 8-angle unit PCB (just remove it from its case). Thats the easiest to get started. The other frontpanel breaks out two potentiometers of the 8-angle unit as external potentiometers.
I removed the pots from the original unit and soldered two external pots. 
If you just want to try out the code first, just connect amyboard, OLED and 8-angle unit and upload the code. 
You'll have a fully working unit.

## 1. Parts
See `docs/BOM.md`.

## 2. Print the panel and knobs
There are **two front-panel variants** in `hardware/panel/`:
- `Eltro_MK3_Panel_Stock8Angle.stl` — for an unmodified 8Angle unit (PCB
  still in its own case). This is the easiest to build.
- `Eltro_MK3_Panel_ExternalPots.stl` — breaks out two of the 8Angle's
  potentiometers as external pots on the panel (its own pots desoldered and
  wired out). This is what this build uses.

Knob STLs are in `hardware/knobs/`.

I used PETG filament on a Bambu Lab P2S with a standard 0.4mm nozzle. No
supports were needed.

The 8Angle PCB and OLED are mounted to the panel with hot glue.

## 3. Wire the front-panel bus
- M5Stack 8Angle and SH1106 OLED both go on the AMYboard's **front-panel**
  Grove I2C port (SDA = GPIO 17, SCL = GPIO 18) — not the back "host" port.
  You need to solder or get a Y-cable for the 4 I2c pins to connect both peripherals.

See `docs/TECHNICAL_NOTES.md` for the full I2C address table and the
electrical notes on MIDI out.

## 4. Set up the Arduino toolchain
1. Install Arduino IDE and add the AMYboard board support (arduino-esp32
   core **3.3.8 or newer** — the AMYboard board target doesn't exist in
   older core versions).
2. Install the AMY library, **version 1.2.14+ or `main`**
   (github.com/shorepine/amy) — via Library Manager or "Add .ZIP Library."
3. Keep the core and AMY library versions in step; see the toolchain note in
   `docs/TECHNICAL_NOTES.md` if you hit distorted audio-in after an update.

## 5. Flash the firmware
1. Open `firmware/eltro_mk3_v12/eltro_mk3_v12.ino` in the Arduino IDE
   (`eltro_font5x7.h` must sit alongside it in the same folder).
2. Select the AMYboard target board.
3. Upload.
4. On boot, the serial monitor should print a `Ready [BUILD: ...]` marker —
   confirm it matches the version you flashed.

## 6. First power-up checklist
- Confirm audio passes through in bypass before enabling the effect.
- CV inputs float at a non-zero voltage when unpatched — keep CV amount at 0
  on Page B until a cable is patched in, or calibrate first (see
  `docs/TECHNICAL_NOTES.md`).
- For full operating instructions once it's running, see
  `docs/manual/Eltro_MK3_Manual.pdf`.

## 7. Mount in the case
The skiff case STL is in `hardware/case/` — it's a remix of a third-party
CC BY 4.0 design, see `hardware/CASE_NOTE.md` for attribution and what was
changed.

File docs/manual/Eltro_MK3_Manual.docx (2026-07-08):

# Eltro MK3 Manual

A Eurorack recreation of the Eltro Tempophon

# Eltro MK3

A Eurorack recreation of the Eltro Tempophon rotating-head tape machine.

## What this instrument is


The Eltro MK3 front panel.

In the late 1950s, the German engineer Anton Springer built a remarkable machine in Heidelberg. Labeled as the Tempophon — later also as the “Information Rate Changer” or simply the “Springer machine” — it did something no tape recorder could: it changed the pitch of a sound without changing its speed, and changed its speed without changing its pitch. For the first time, time and pitch came apart.

It achieved this mechanically. A loop of magnetic tape carried the recorded sound past a spinning drum with four playback heads, set 90° apart so that one head was always in contact with the tape. As the drum turned, each head swept a short stretch of tape, handed off to the next, and lifted away. By running the tape at one speed and spinning the head drum at another, the machine read the recording at a relative speed — repeating little tape segments to stretch time, dropping them to compress it, all while pitch was controlled separately by the head motion.

If that sounds otherworldly, it is: the Tempophon gave HAL 9000 his voice in Kubrick’s 2001: A Space Odyssey, most audibly as he slows and warbles in the death scene. It was a favourite of musique concrète composers too.

The Eltro MK3 is a faithful electronic digital recreation of that machine, built for Eurorack. It behaves like the original — same controls, same physics, same sound — so this manual describes it the way you’d describe the real thing: a tape loop, a head drum, playback heads riding on tape. The Eltro MK3 version adds things the original never had such as reverse playback, voltage control, MIDI.

### How the recreation maps to the real machine

On the original Tempophon | In the Eltro MK3
Loop of pre-recorded magnetic tape | A continuously re-recorded loop held in a ring buffer in memory (“the tape”)
The recording that’s on the tape | Your live audio input, laid down by a recording head as it comes in
Rotating drum with 4 playback heads at 90° | Four playback heads sweeping the tape loop
Tape transport speed | The tape speed control
Head-drum rotation speed | The drum control
Repeating / dropping tape segments to reconcile the two speeds | The same — done seamlessly, with the heads crossfading as they hand off

Once you picture the tape loop and the spinning heads, the controls explain themselves.

## Getting sound through it

1. Patch an audio source into line in.
2. Patch line out to your mixer or interface.
3. Set the bypass switch (far left) to the active position.
4. Bring up input gain until you hear signal, and set output gain to taste.
5. Set tape speed just around +1.00 and drum near 0.00. You’ll hear your sound played back off the tape loop.
6. Slowly turn drum. The pitch shifts while the sound keeps moving through the tape at the same rate. That separation — pitch moving while time holds — is the whole trick the Tempophon was built for.

If nothing comes through, see the When something’s wrong section at the end.

## The heart of the Eltro MK3: tape speed and drum speed

Everything the instrument does comes from two speeds: how fast the tape loop runs, and how fast the head drum spins. What you hear is the difference between them — exactly as on the original machine.

Picture it physically: the tape carries your recording past the heads. If the heads spin with the tape at a matching speed, they stay over the same point and the sound stands still. If they move against the tape, they read across it faster or slower than it was recorded, and the pitch shifts.

- Tape speed — how fast the tape loop runs past the heads. This is your time control: how quickly you travel through the recording. Centre detent = the tape is stopped. Turn one way for forward motion, the other for reverse.
- Drum speed — how fast the head drum spins against the tape. Together with tape speed, this sets the pitch. Centre detent = drum stopped.

What you hear, in physical terms:

Tape and drum | What happens
Same speed | Silence / freeze — the heads ride along with the tape, holding one point. (True at any matched speed, including both stopped.)
Drum trailing the tape by the “recording” amount | Plays back at the original pitch
Far apart | Large pitch shift
Drum spinning faster than the tape | The heads read backwards across the tape — reverse
Tape stopped, drum spinning | You sit on one spot of the recording while the pitch sweeps around it
Tape running, drum near centre | You scan through the recording at close to natural pitch

The two big controls are worth living on. Small moves near centre give musical, speech-like inflections (this is how HAL was made); large moves give dramatic sweeps, freezes, and reversals.

The screen shows both speeds with a bar for each. Little letters or symbols may appear beside them — see Reading the screen.

## The rest of the panel

### Bypass (far left)

Switches the effect in and out; in bypass you hear the dry input. Note that the recording head keeps laying sound onto the tape loop even in bypass, so when you switch the effect back in, the heads pick up on live, current sound last recorded.

### The performance controls (Page A)

Left to right across the panel:

Control | What it does, in tape terms
Tape speed | Speed of the tape loop past the heads — the time axis (see above).
Drum speed | Speed of the head drum — sets pitch against the tape (see above).
Overlap | How much neighbouring playback heads blend as they hand off the tape from one to the next. Low = a harder, choppier handoff you can hear; high = a smoother, more washed blend. Higher overlap trades a little sharpness for smoothness — see the note below on how that plays differently when stretching vs. compressing time.
Wow | Adds the gentle speed wobble of real tape — the wow and flutter of a mechanical transport. 0 = steady; up = vintage warble.
Input gain | Level of the sound being laid onto the tape. Bring it up if the input is quiet.
Output gain | Overall output level.
Decay | How long sound persists on the tape loop. The recording head blends new input over what’s already there, so with decay up, earlier passes repeat and fade like a tape echo, building and smearing. Low = the tape wipes clean each lap; high = long feedback tails.
Tape length | How much tape is on the loop — from a very short loop up to about 20 seconds. A short loop is tight and immediate; a long loop gives you more recorded material to roam through.

### Head-segment size and drum range (Page B)

A second page holds setup controls you’ll set once and mostly leave. Reach it by serial command p or MIDI CC65 (see below). The knobs use pickup mode: turning a knob does nothing until it passes the stored value, so nothing jumps when you arrive. The bottom of the screen shows which knobs are “live.”

The two most musical Page B controls:

- Segment length — how much tape each head reads before handing off to the next: the length of the tape segments the machine repeats or drops. Short segments sound textured and buzzy; long segments sound smooth and fluid. A recommended default for starting out is around 40ms. This is a major tone control, working hand in hand with overlap.
- Tape range and drum range — how far the tape-speed and drum-speed knobs reach on Page A. Widen them for extreme sweeps, narrow them for fine control.

The remaining Page B knobs configure CV and MIDI, below. Everything on Page B is saved and remembered when you power off.

## Reading the screen

The main page shows the current tape speed and drum speed, each with a bar. A small marker may appear beside them:

- c — a CV input is set up to move that control (see CV).
- › (a small right-arrow) — that control is currently being driven by MIDI; the physical knob is ignored until you turn it (see MIDI).

The speed numbers show the actual speed in play, including any CV — so you can watch a patched voltage source move them in real time.

The two screens you’ll see — the performance page (Page A) and the setup page (Page B):

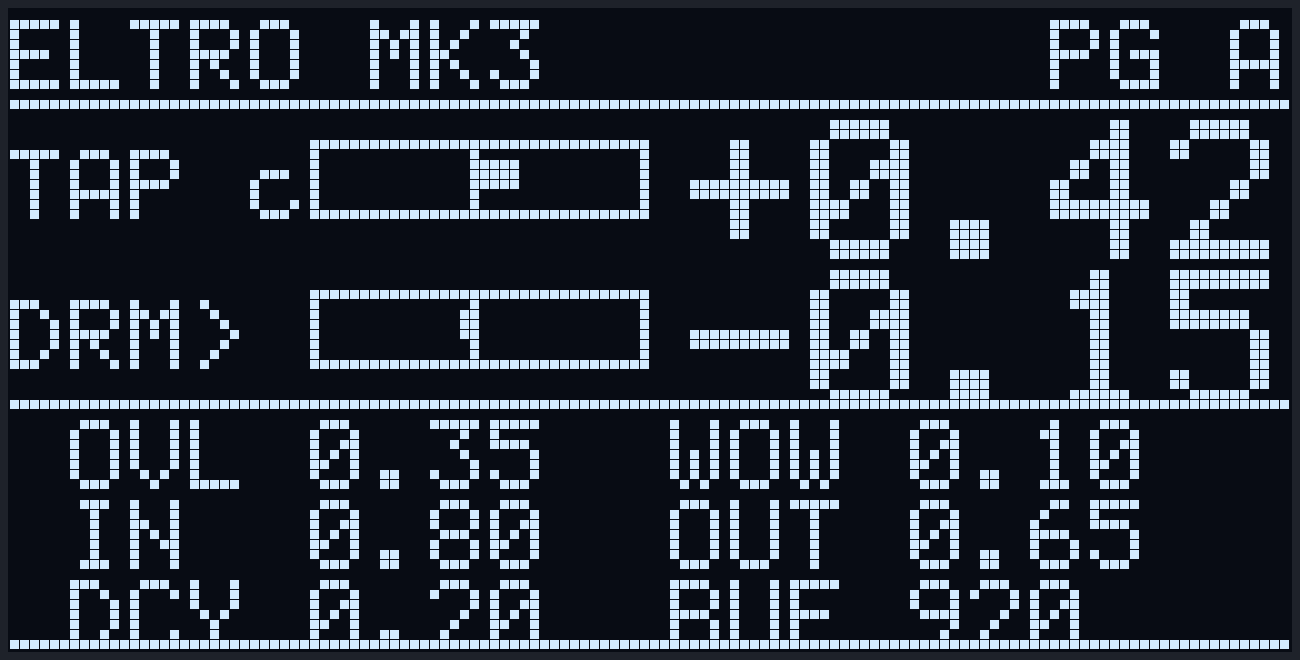
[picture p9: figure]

The performance page (Page A): tape and drum gauges with their live speed values on top, and the six secondary controls below. Here a › marks the drum as MIDI-driven and a c marks a CV armed on the tape axis.

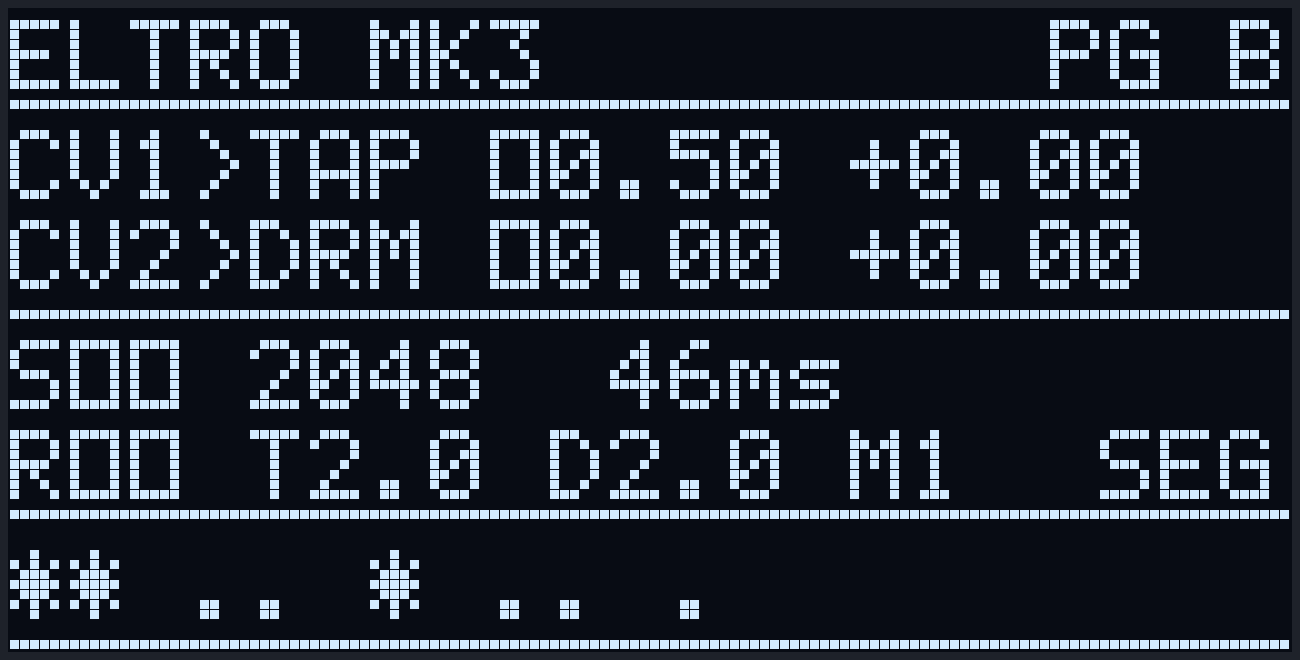
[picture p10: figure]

The setup page (Page B): the two CV assignments, segment length, the tape/drum ranges and MIDI channel, and — along the bottom — the pickup markers for each setup knob (*=live, .=waiting).

## Voltage control (CV)

Beyond what the original machine could do, the MK3 lets you steer the two speeds with control voltage — patch an LFO, envelope, or sequencer to sweep them hands-free.

- CV 1 moves the tape speed; CV 2 moves the drum.
- On Page B, turn up the CV amount for the input you’re using (and set an offset if you want a fixed shift). At zero amount, CV does nothing.
- When an input is armed, a small c shows beside that control on the main page, and the speed reading moves as the voltage comes in.

Leave the CV amount at zero (page B setting) when nothing is patched to that input — an unconnected input can drift and nudge the speed on its own.

## MIDI

The Eltro MK3 both receives and sends MIDI over the two TRS MIDI jacks (in and out), so it fits into a DAW or sequencer rig in both directions. Set the channel on Page B (it’s shown there as M followed by a number); the same channel is used for both receiving and sending.

### Receiving (MIDI in)

Drive the Page A controls from a keyboard, sequencer, or DAW. The eight Page A controls respond to these CC numbers on the chosen channel:

CC | Control
102 | Tape speed
103 | Drum
104 | Overlap
105 | Wow
106 | Input gain
107 | Output gain
108 | Decay (feed-back)
109 | Tape length
65 | Switch Page A / B (value 64+ = Page B)

When a control receives MIDI it’s taken over — a small › (right-arrow) shows beside it and the physical knob is ignored until you turn it, at which point your hand takes back control. This is per-control, so you can automate the tape speed from a sequencer while shaping overlap by hand.

The MK3’s MIDI in accepts either type of TRS MIDI cable (Type A or Type B) — you don’t have to match a convention, either works.

### Sending (MIDI out)

Turn a Page A knob by hand and the MK3 sends the matching CC (the same CC numbers as the table above), on the Page-B channel, out the MIDI out jack. So you can record a performance into your DAW just by playing the panel, and play it back into the module later.

A few things worth knowing:

- Only physical knob moves are sent. A control that’s currently being driven by incoming MIDI (showing ›) does not echo back out — so looping the MK3 through a DAW and back won’t create a feedback storm.
- It sends knob position, so a move you record and play back reproduces the same sound.
- The MIDI out jack is standard TRS MIDI; use a Type-A TRS cable (or a Type-A TRS→DIN adapter for 5-pin gear).

## Playing it

- Live near centre. The tape and drum controls are most expressive close to their centre detents. This is the register where the Tempophon made voices — small inflections of pitch and time.
- Freeze. Match tape and drum speeds and the sound holds on a single point of tape — a drone or a frozen texture.
- Reverse smear. Spin the drum faster than the tape for backward reading; add overlap and decay for a ghostly wash.
- Segment length is your texture knob. Short tape segments buzz and granulate; long ones flow. Set it against overlap to move between gritty and glassy.
- Match overlap to which way you’re stretching time. When you’re stretching time — tape speed between stopped and its natural forward rate (slower than the original), so the machine is repeating segments to fill the gaps — raise the overlap. The extra blend hides the repeated seams and makes the stretched sound noticeably more natural. When you’re running faster than natural (tape speed past unity, dropping segments), that same high overlap reads as a slight blur, so back it off for a cleaner, more defined sound. Rule of thumb: stretching wants more overlap, speeding-up wants less.
- Decay builds worlds. Turned up, the tape loop feeds back on itself — echo tails, swells, and dense clouds.
- A touch of wow gives the whole thing the breath of real tape.

## When something’s wrong

No sound - Check bypass is in the active position. - Bring up input gain — the input runs a little quiet and often wants a healthy amount. - Confirm line in and line out are patched. - If tape and drum are at the same speed, silence is correct — that’s the freeze point. Move one of them.

Sound is there but frozen - Tape speed at centre means the tape loop is stopped. Turn it off centre to travel through the recording.

A knob does nothing - Look for a small › (right-arrow) beside it — MIDI has taken it over. Turn the knob to reclaim it. - On Page B, knobs must be turned past their stored value before they respond (pickup mode).

MIDI out isn’t reaching my gear - Confirm the receiving device is set to the same channel shown on Page B. - Remember only hand-moved knobs send — a knob under MIDI control (›) stays silent on the output by design. - Use a Type-A TRS MIDI cable/adapter on the out jack.

Distortion / crackle - Ease off input and/or output gain. High decay also builds up energy on the tape loop and can push into clipping — lower it if things get harsh.

Silence for a while after powering on with a long tape - A long tape loop takes a moment to fill with sound before there’s anything to play back — like a tape spooling up. Give it a few seconds, or use a shorter tape length.

## At a glance

Tape speed = time (how fast the tape runs). Drum speed = pitch (the heads against the tape). Same speed = silence. Everything else colours or levels that.

Page A: tape speed · drum · overlap · wow · input gain · output gain · decay (feed-back) · tape length Page B (setup, saved): CV1 amount · CV1 offset · CV2 amount · CV2 offset · segment length · tape range · drum range · MIDI channel

CV 1 → tape speed, CV 2 → drum. MIDI CC 102–109 ↔ the eight Page A controls (received and sent). MIDI in takes either TRS type; MIDI out is Type-A.

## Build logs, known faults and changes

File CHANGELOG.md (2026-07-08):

# Changelog

All notable changes to the Eltro MK3 firmware, newest first.

## V12 (current)
- Page-A knobs now use pickup ("catch") mode on page re-entry, matching
  Page B: returning to Page A no longer snaps a parameter to the pot's
  physical position. Page A is still live at boot.
- OLED MIDI-owned marker changed from `M` to `>`.

## V11
- MIDI TX added: the eight Page-A knobs emit their CCs (102–109) on physical
  movement, so a DAW/sequencer can record and play back knob motion.
- TX is driven differentially (see `docs/TECHNICAL_NOTES.md`) so it reaches
  DIN-4/5 MIDI interfaces cleanly.
- Guarded against RX/TX feedback: TX only fires on real pot movement and
  skips any knob currently MIDI-owned.

## V10
- Read heads phase-locked to a single master scan phase instead of four
  independent per-head accumulators. Fixes a bug where changing the buffer
  or segment length at runtime permanently collapsed the head stagger,
  causing a stutter. Steady-state sound is unchanged from V9.

## V9
- Two CV inputs added (CV1 → tape, CV2 → drum), read via an ADS1115.
- Full MIDI RX layer: CC control of all Page-A knobs with per-knob catch
  takeover.

## V8
- Core two-axis DSP established: progression (time) and pitch
  ((tape − drum)) as independent axes — the defining feature of the
  instrument. See `docs/TECHNICAL_NOTES.md` for the full model.

## Earlier
- V6/V7: single read-velocity precursors; V7 fixed a silence bug at
  tape == drum but still coupled pitch and progression to one number.

---

Hardware milestones:
- Cold-boot audio-in latch fixed — root cause was I2C access before
  `amy_start()`; see `docs/TECHNICAL_NOTES.md`.
- Independent knob-direction flag, on-screen output gain, decluttered
  gauge row.

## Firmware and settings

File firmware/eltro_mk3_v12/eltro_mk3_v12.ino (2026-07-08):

/**
 * eltro_amyboard.ino  (V12)
 * Eltro MK3 "Information Rate Changer" — AMYboard + M5Stack 8Angle + SH1106
 * Analog pass-through: AUDIO IN → Eltro DSP → AUDIO OUT
 *
 * V12 change vs V11: Page-A knobs now use PICKUP (catch) mode on page RE-ENTRY,
 * mirroring Page B. Previously, returning to Page A snapped every Page-A parameter
 * to its physical pot position (a jump). Now, when Page A is (re)entered, all eight
 * knobs are armed "waiting" at their current reading and a knob does not drive its
 * parameter until moved past PAGEA_PICKUP_THRESH — so values held while you were on
 * Page B (or set by MIDI) are preserved until you deliberately grab a knob.
 * BOOT EXCEPTION: at power-on Page A is LIVE (knobs take their physical position
 * immediately), matching the familiar "panel is live at startup" feel; pickup only
 * applies on subsequent re-entries. Page B is unchanged (it pickups on boot too,
 * because its values are persisted). See rearmPageACatch() / potDrivesPageA().
 *
 * V11 change vs V10: MIDI TX added (knob → CC out). The eight Page-A knobs emit
 * their CCs (102–109) when PHYSICALLY moved, so a DAW/sequencer can record and
 * play back knob motion. Two guards prevent an RX/TX feedback loop: TX runs only
 * on real pot movement (the existing POT_DEADBAND / any_changed path), and skips
 * any knob currently MIDI-owned (s_midiOwned[]) so an incoming CC is never echoed
 * back out. Deadband = 7-bit re-quantization (emit only when the 0..127 value
 * changes). Serial1 now inits with a TX pin (was -1). TX pin is a single #define
 * (ELTRO_MIDI_TX_PIN) — the loop is driven DIFFERENTIALLY (TX normal on 14, its
 * hardware-inverted mirror on 15) so a DIN-4/5 opto input receives cleanly; see
 * the note there.
 * Everything else is byte-identical to V10; DSP/ordering/phase-lock untouched.
 * V10 kept as the stable fallback.
 *
 * V10 change vs V9: the four read heads are now PHASE-LOCKED to a single master
 * scan phase (each head derived as master + (arcLen/NUM_HEADS)*h) instead of four
 * independent scan accumulators. This fixes a bug where changing the buffer (or
 * segment) length at runtime permanently collapsed the head stagger — the heads
 * bunched up and produced a stutter that survived a full buffer rewrite. Steady-
 * state sound is identical to V9 (verified off-board); only the buffer-change
 * robustness changed. V9 kept as the stable fallback.
 *
 * Hardware:
 *   AMYboard (ESP32-S3, 44.1kHz / 16-bit stereo / 256-sample blocks)
 *   M5Stack 8Angle (I2C 0x43) on AMYboard FRONT-panel Grove I2C (SDA=17, SCL=18)
 *   SH1106 128×64 OLED (I2C 0x3C) on same Grove bus
 *   CV1 jack → tape axis, CV2 jack → drum axis; both read via ADS1115 (I2C 0x48, A0/A1)
 *  
 * AUDIO ARCHITECTURE — insert effect via amy_external_render_hook:
 *   AMY calls the render hook once per audible oscillator BEFORE the block
 *   is summed and sent to I2S. We instantiate one oscillator (osc 0) as
 *   the external-buffer path (AUDIO_EXT0/1). Input is pulled with
 *   stereo) holds the live ADC input; we mix to mono, run the Eltro DSP,
 *   and write the mono result into AMY's per-osc SAMPLE buffer, returning 1
 *   ("handled") so AMY mixes our output to AUDIO OUT.
 *
 *   NOTE: write_samples_fn is NOT used for processing — it is a downstream
 *   tap that runs after I2S TX and cannot alter the output.
 *
 * Physics model (V8 — faithful Tempophon, TWO INDEPENDENT AXES):
 *   The buffer is a pre-written tape: one write head, constant +1.0, unit density,
 *   independent of everything (tape speed does NOT touch the write).
 *   Reading is split into the two mechanisms the real machine uses to decouple
 *   time from pitch:
 *     PROGRESSION (time): a grab playhead walks through the buffered tape at the
 *       TAPE rate. How fast you move through the recording. Depends on tape ONLY.
 *     PITCH: within each grabbed segment, the read scans the material at the
 *       RELATIVE velocity (tape − drum). Re-pitches without changing progression.
 *   Each head grabs a fresh segment at the (tape-advanced) grab playhead, scans it
 *   at (tape − drum), and hands off to the next head with a Hann crossfade.
 *   Segments repeat/drop to reconcile the two rates — Carlos's "itty-bitty bits,
 *   cross-faded." Consequences (all validated off-board):
 *       tape == drum      → scan frozen → SILENCE/FREEZE
 *       tape − drum == 1  → scans at write density → recorded pitch (unity)
 *       drum  > tape      → reverse scan within the grain
 *       tape fixed, drum varied → SPEED HOLDS, PITCH MOVES (the decoupling)
 *       tape == 0         → grab frozen → freeze on a spot
 *   This is a grain-based engine (V7 was a single continuous scan): segment length
 *   (Page-B K2) and overlap (Page-A K2) are now the key tone controls. Real-time
 *   single-pass ⇒ the decoupling operates over BUFFERED tape (up to ~20 s of
 *   recorded history), not a live stream — we can re-scan the past, not the future.
 *
 * Head geometry (V8 — grain engine, not a physical hard-switch):
 *   The original drum has 4 heads at 90° spacing with one always in contact,
 *   so the real machine hands off near-instantaneously. V8 does NOT model that
 *   as a hard switch: the two-axis grain engine reconciles progression and pitch
 *   by repeating/dropping segments, and that handoff MUST be crossfaded or the
 *   seams click. Overlap (Page-A K2) is therefore a real tone control, not a
 *   near-zero authenticity detail: range 0.10–0.95, default 0.25. Below ~0.10
 *   the granular seams become audible. Higher values smooth the grain further.
 *
 * Decay (erase):
 *   ring[wi] = input*(1-decay) + ring[wi]*decay
 *   0.0 = full erase (normal pass), ~1.0 = infinite loop accumulation
 *
 * Wow/Flutter combined:
 *   wow = K3 value, flutter = wow * 0.6 (fixed ratio, shallower)
 *
 * Page A (slider OFF, LEDs blue) — main controls:
 *   K0  Tape speed    −range – +range  (centre detent = 0 = stopped; range = Page-B K5)
 *   K1  Drum speed    −range – +range  (centre detent = 0 = stopped; range = Page-B K6)
 *                     Both knobs use an exponential taper (g_speedGamma, default
 *                     2.0) so the dense −1..+1 region gets more travel; set live
 *                     via serial 'g' (e.g. "g2.5"), persisted to NVS.
 *   K2  Head overlap   0.10 – 0.95  (default 0.25; below ~0.10 seams click)
 *   K3  Wow/Flutter    0.0  – 0.05
 *   K4  Input gain     0.0  – 4.0   (raised from 2.0 for the quiet AMYboard input)
 *   K5  Output gain    0.0  – 1.5
 *   K6  Decay          0.0  – 0.9999
 *   K7  Buffer length  512  – 884736 samples (~12 ms – 20 s, log scale)
 *   Toggle (latching slider) → bypass OFF/ON (dry passthrough; the tape keeps
 *                              recording in bypass — decay forced 0 — so un-
 *                              bypassing resumes on live material, not a freeze)
 *
 * Page B (via Serial 'p' or MIDI CC 65) — config:
 *   K0  CV1 scale     0.0 – 4.0   (CV-in 1 → TAPE axis)
 *   K1  CV1 offset   −2.0 – +2.0  (CV-in 1 → TAPE axis)
 *   K2  CV2 scale     0.0 – 4.0   (CV-in 2 → DRUM axis)
 *   K3  CV2 offset   −2.0 – +2.0  (CV-in 2 → DRUM axis)
 *   K4  Segment len    64 – 32768 samples (~1.5–743 ms) — absolute, independent
 *                       of buffer; short=textured/buzzy, long=smooth/fluid
 *                       (default 4096 ≈93ms; lower=shorter/textured, higher=longer)
 *   K5  Tape range    1.0 – 5.0   — full-scale of Page-A tape knob (±)
 *   K6  Drum range    1.0 – 5.0   — full-scale of Page-A drum knob (±)
 *   K7  MIDI channel  1 – 16      — RX filter (and future TX channel)
 *
 * MIDI RX (V9): byte-at-a-time parser (running-status aware, real-time bytes
 *   skipped). Fixed CC map on the Page-B K7 channel, all 7-bit, each mapped
 *   through the SAME law as its knob (so CC == equivalent knob position):
 *     CC102=tape  CC103=drum  CC104=overlap  CC105=wow  CC106=in gain
 *     CC107=out gain  CC108=decay  CC109=buffer   (CC65 = page toggle)
 *   Per-knob "catch" takeover: a CC owns its knob until the pot moves past
 *   MIDI_CATCH_THRESH (60/4095); OLED shows '>' by MIDI-owned Page-A knobs.
 *   TX (knob→CC, deadband) is a planned stage 2; jack wired, code still RX-only.
 *
 * Serial commands: 'p' = toggle Page A/B; 'g<value>' = set speed-knob taper
 *   gamma (1.0–4.0, e.g. "g2.5"; bare 'g' prints current). Both persist to NVS.
 *
 * USB SERIAL NOTE:
 *   The AMYboard's board definition does not set ARDUINO_USB_CDC_ON_BOOT, and
 *   exposes no "USB CDC On Boot" Tools menu option to enable it. Without this,
 *   plain Serial never attaches to the native USB peripheral — confirmed by
 *   testing (zero output, in any terminal app, with no errors) and by tracing
 *   Espressif's usb_cdc.h docs, which show this exact scenario requires a
 *   manually instantiated USBCDC object + USB.begin(). We alias Serial to that
 *   object via #define so the rest of the sketch needs no further changes.
 *   Serial1 (TRS MIDI UART, separate hardware) is unaffected by this.
 *
 * Libraries needed (Arduino Library Manager):
 *   AMY (Arduino Library Manager). No display library — the SH1106 OLED
 *   is driven by a small built-in direct-I2C driver (see eltro_font5x7.h).
 */

#include <AMY-Arduino.h>
#include <Wire.h>
#include <math.h>
#include <string.h>
#include <Preferences.h>   // ESP32 NVS flash storage for persistent Page-B settings
#include "esp_heap_caps.h" // PSRAM allocation for the ring buffer (V5 test)
#include "USB.h"
#include "esp_rom_gpio.h"     // esp_rom_gpio_connect_out_signal — MIDI TX inverted mirror
#include "soc/uart_periph.h"  // uart_periph_signal[] — UART1 TX signal index
#include "hal/gpio_hal.h"     // gpio_set_direction

// AMYboard's board definition does not set ARDUINO_USB_CDC_ON_BOOT, so plain
// Serial never attaches to the native USB peripheral on this board — confirmed
// by tracing Espressif's usb_cdc docs and testing. We must instantiate the CDC
// interface manually and call USB.begin() ourselves. Serial1 (TRS MIDI UART)
// is a separate peripheral and is unaffected by this.
#if !ARDUINO_USB_CDC_ON_BOOT
USBCDC USBSerial;
#define Serial USBSerial
#endif

// ═══════════════════════════════════════════════════════════════════════════════
// 1.  CONSTANTS
// ═══════════════════════════════════════════════════════════════════════════════

#define SAMPLE_RATE        AMY_SAMPLE_RATE
#define BLOCK_SIZE         AMY_BLOCK_SIZE
#define NUM_HEADS          4
// V5 PSRAM TEST: ring buffer in PSRAM (8MB on this board), 5 s. This re-tests
// PSRAM now that the O(bufLen/segLen) wrapf cost is fixed — the earlier "PSRAM
// too slow" verdict was contaminated by that loop bug. 221184 = 5.01 s @44.1k,
// divisible by NUM_HEADS and 2. Minimal change: only the buffer moved, no DSP
// reorder. If this holds 172/s, PSRAM is viable and we can go larger.
// Ring buffer in PSRAM (8MB on this board), 20 s. PSRAM works fine for the audio
// buffer once the per-sample wrapf cost was fixed (the earlier "PSRAM too slow"
// verdict was that loop bug, not memory latency). 884736 = 20.06 s @44.1k,
// divisible by NUM_HEADS and 2. Uses ~1.69 MB of the 8 MB PSRAM. Confirmed on
// hardware: holds 172 blocks/s across all buffer and segment sizes.
// Note (V7): read heads roam the whole buffer freely by (tape−drum); they start
// at bufLen/2 once at init, then move independently. The buffer takes ~20 s to
// fully populate from cold, so there is a startup-fill transient at large buffers.
#define RING_BUF_MAX       884736  // ~20.06 s at 44.1k, in PSRAM
#define RING_BUF_MIN       512

// Segment length is ABSOLUTE (a fixed sample count), independent of buffer length,
// so changing the buffer doesn't disturb the grain character. Set on Page B K2,
// linear in samples. ~1.5 ms (granular/buzzy, by choice) up to ~743 ms (smooth).
// Default ~4096 = 93 ms = the v0.x character.
#define SEG_MIN            64       // ~1.5 ms — granular/buzzy (intentionally reachable)
#define SEG_MAX            32768    // ~743 ms — long/smooth
#define SEG_DEFAULT        4096     // ~93 ms — matches original v0.x feel

#define ANGLE8_ADDR        0x43
#define ANGLE8_POTS        8

// ── CV input: ADS1115 16-bit ADC ────────────────────────────────────────────
// Official AMYboard CV-in hardware (tulipcc docs/amyboard/modular.md): two CV
// input jacks on an ADS1115 at I2C 0x48, accepting ±10 V at the jack. It sits on
// the same front Grove bus the uiTask already owns, so no extra bus/mutex.
// We read CV-in 1 (A0) → g_cv1Value and CV-in 2 (A1) → g_cv2Value, each mapped
// 1 unit per volt and clamped to ±5.0 (the musical reference swing). They fold
// into the two axes in eltroProcess via:
//   effectiveTape = tape + cv1Value*cv1Scale + cv1Offset   (CV1 → tape, faithful)
//   effectiveDrum = drum + cv2Value*cv2Scale + cv2Offset   (CV2 → drum)
// CV1 acts as a remote tape knob: effectiveTape is used everywhere tapeSpeed is
// (both progression AND the tape−drum pitch term), so CV1 and the tape knob
// behave identically.
#define ADS1115_ADDR       0x48
#define ADS1115_CH_CV1     0       // CV-in 1 = single-ended A0 (→ tape)
#define ADS1115_CH_CV2     1       // CV-in 2 = single-ended A1 (→ drum)
#define CV_READ_MS         10      // throttle EACH channel's read to ~100 Hz in uiTask
#define CV_CLAMP           5.0f    // |cvValue| ceiling (±5 V reference swing)
#define CV_EMA_ALPHA       0.25f   // light smoothing on the CV read (0=frozen,1=raw)
// Volts-per-count for the ADS1115 at the ±6.144 V PGA setting (FS = 2^15 counts).
// CALIBRATION: this assumes the board's front-end presents the CV within the
// ADC's ±6.144 V window. If a known input voltage reads wrong, this is the ONE
// constant to trim — measured_volts / raw_count. (±6.144V / 32768 ≈ 187.5 µV.)
#define ADS1115_V_PER_COUNT (6.144f / 32768.0f)

// AMYboard front-panel Grove I2C bus (accessories). NOT the back "Tulip" host port.
// Source: AMYboard accessories docs — SDA=17, SCL=18, 400kHz.
#define I2C_SDA_PIN        17
#define I2C_SCL_PIN        18
#define I2C_SCAN_MS        12
#define POT_DEADBAND       10
#define LED_FLASH_MS       60

// ── V9 MIDI: fixed CC map for Page-A knobs (RX; TX added later) ───────────────
// Eight contiguous CCs in the "undefined" range 102–119 (reserved by the MIDI
// spec for exactly this, so they won't collide with standard controllers like
// mod=1, volume=7, expression=11, sustain=64, or the mode messages 120–127).
// CC65 stays the page toggle (unchanged). Each CC drives the same parameter as
// the matching Page-A pot, mapped through the SAME law (taper for tape/drum, log
// for buffer) so a CC value and the equivalent knob position produce identical
// results — MIDI and hand are interchangeable.
#define MIDI_CC_TAPE    102
#define MIDI_CC_DRUM    103
#define MIDI_CC_OVERLAP 104
#define MIDI_CC_WOW     105
#define MIDI_CC_INGAIN  106
#define MIDI_CC_OUTGAIN 107
#define MIDI_CC_DECAY   108
#define MIDI_CC_BUFLEN  109
#define MIDI_CC_PAGE    65        // existing page-toggle CC (Page A/B)

// ── V11 MIDI TX pins (differential drive) ────────────────────────────────────
// MIDI IN is on AMYBOARD_MIDI_IN (GPIO 21). MIDI OUT is a TRS current loop the
// AMYboard brings to TWO GPIOs, one per contact (src/amy.h):
//     #define AMYBOARD_MIDI_OUT_TYPE_A 14   // -> tip -> DIN pin 5
//     #define AMYBOARD_MIDI_OUT_TYPE_B 15   // -> ring -> DIN pin 4
// A DIN-4/5 opto input needs BOTH loop legs actively defined. Single-ended (one
// pin driven, other floating) never closes the loop -> silence. A static-LOW
// return closes it but with marginal levels/edges -> the byte stream arrives
// GARBLED (a picky interface like the MOTU M2 mis-samples it).
// BENCH-CONFIRMED FIX (clean CC102 into the M2): drive the loop DIFFERENTIALLY —
//   GPIO14 = UART1 TX, NORMAL   (data / source leg)
//   GPIO15 = UART1 TX, INVERTED (active return leg, via the ESP32-S3 GPIO matrix)
// The receiver opto then sees a full push-pull swing with clean, bit-aligned
// edges. Orientation matters: TX must be on 14 and the inverse on 15 (the reverse
// garbles). This is set up in setup(); see the esp_rom_gpio_connect_out_signal()
// call. RX is unaffected.
#define ELTRO_MIDI_TX_PIN     14   // UART1 TX, normal  — data leg (tip, DIN pin 5)
#define ELTRO_MIDI_RETURN_PIN 15   // UART1 TX, INVERTED — active return (ring, DIN pin 4)

// Per-knob catch takeover on Page A: an incoming CC owns the parameter until the
// physical pot is moved past this raw-ADC threshold (of 4095). Larger than the
// Page-B value (40) because these are live-performance knobs a hand rests on —
// a small accidental brush shouldn't yank a MIDI-automated value back.
#define MIDI_CATCH_THRESH 60

#define DISPLAY_MS         100   // 10 fps. Display runs on core 0 (uiTask), so the
                                 // ~100ms OLED flush no longer affects audio.

// ═══════════════════════════════════════════════════════════════════════════════
// 2.  SHARED STATE
// ═══════════════════════════════════════════════════════════════════════════════

volatile float    g_tapeSpeed   =  1.0f;   // tape transport speed (the recorded tape moving past the heads)
volatile float    g_drumSpeed   =  0.0f;   // drum (head rotor) speed

// Faithful Tempophon model (V6): the read-through speed = (tape − drum).
//   SILENCE when tape == drum (no relative motion — heads ride with the tape).
//   UNITY PITCH (plays at recorded pitch) when (tape − drum) == 1.
//   drum > tape → reverse scan; drum opposing tape → pitch up; etc.
// READTHRU_UNITY is the (tape − drum) value that reproduces original pitch.
#define READTHRU_UNITY (1.0f)
volatile float    g_overlap     =  0.25f;   // V8: granular needs real overlap to hide segment seams (V7 used 0.03 for continuous scan)
volatile float    g_wow         =  0.0f;
volatile float    g_inputGain   =  1.0f;
volatile float    g_outputGain  =  0.8f;
volatile float    g_decay       =  0.0f;
volatile uint32_t g_bufLen      =  RING_BUF_MAX;

// CV1 → tape axis, CV2 → drum axis. Scale/offset per channel (Page B K0/K1 for
// CV1, K2/K3 for CV2). Values driven by serviceCvInput() in uiTask.
volatile float    g_cv1Scale    =  1.0f;
volatile float    g_cv1Offset   =  0.0f;
volatile float    g_cv1Value    =  0.0f;   // ADS1115 A0, ±5 unit clamp → tape
volatile float    g_cv2Scale    =  1.0f;
volatile float    g_cv2Offset   =  0.0f;
volatile float    g_cv2Value    =  0.0f;   // ADS1115 A1, ±5 unit clamp → drum

// Speed-knob ranges (Page B K3/K4, each 1.0–5.0). Page-A tape and drum knobs are
// SYMMETRIC about a centre detent at 0: tape -range..+range, drum likewise.
// Centre (0) = stopped. Unity pitch = drum==tape; normal play at unison = both
// equal & positive. Larger range = wider throw.
volatile float    g_tapeRange   =  1.0f;
volatile float    g_drumRange   =  1.0f;

// Speed-knob taper (tape + drum). The bipolar tape/drum knobs are reshaped by an
// exponential curve so the musically dense −1..+1 region around centre gets more
// knob travel, instead of being crammed into a small fraction of the throw when
// the range is large. Curve: out = sign(x) * |x|^gamma * range, where x is the
// knob's signed position in [−1,+1]. gamma = 1 is the old linear mapping; gamma
// > 1 expands the centre (finer near 0), gamma < 1 would compress it. Persisted
// to NVS; set live over serial with the 'g' command (e.g. "g2.5"). Bounded to a
// sane range so a bad value can't make the knob unusable.
#define SPEED_GAMMA_MIN  1.0f
#define SPEED_GAMMA_MAX  4.0f
volatile float    g_speedGamma  =  2.0f;   // default: −1..+1 gets ~45% of travel (vs ~20% linear at range 5)

// V9 MIDI receive channel (1–16), set on Page B K7, persisted to NVS. Filters
// incoming channel-voice messages; will also select the TX channel when TX lands.
volatile uint8_t  g_midiChannel =  1;

// Segment length in SAMPLES (Page B K2, SEG_MIN..SEG_MAX, linear). ABSOLUTE —
// independent of buffer length, so the grain character no longer shifts when you
// change the buffer. The four heads space themselves segLen apart (clean tiling).
// ~64 samples (buzzy) .. ~32768 (smooth); default ~4096 (≈93 ms, v0.x feel).
volatile float    g_segLen      =  (float)SEG_DEFAULT;

volatile bool     g_bypass      =  false;
volatile bool     g_pageB       =  false;

volatile uint16_t g_pot_display[ANGLE8_POTS] = {0};
volatile uint8_t  g_last_moved_pot = 255;
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
void loop() {
    static uint32_t last_diag = 0;

    amy_get_input_buffer(s_extBuf);            // grab the ADC input block
    eltroProcessBlock(s_extBuf);               // downmix → Eltro → mono to L+R
    amy_set_external_input_buffer(s_extBuf);    // hand to AUDIO_EXT0/1 oscs
    amy_update();                               // render + I2S write; blocks ~1 block

    uint32_t now = millis();
    if (now - last_diag >= 1000) {
        last_diag = now;
        Serial.printf("[diag] blocks/s=%lu  inPeak=%ld  outPeak=%ld  bypass=%d\n",
                      (unsigned long)g_blockCount, (long)g_inPeak, (long)g_outPeak,
                      g_bypass ? 1 : 0);
        Serial.printf("       dsp: inGain=%.2f outGain=%.2f tape=%.2f drum=%.2f cv1=%.2f cv2=%.2f\n",
                      g_dbgInputGain, g_dbgOutputGain, g_dbgTape, g_dbgDrum, g_cv1Value, g_cv2Value);
        {
            char owned[ANGLE8_POTS + 1];
            for (int i = 0; i < ANGLE8_POTS; i++) owned[i] = s_midiOwned[i] ? ('0' + i) : '-';
            owned[ANGLE8_POTS] = '\0';
            Serial.printf("       midi: ch=%d owned=%s (CC102-109 -> knobs 0-7)\n", g_midiChannel, owned);
        }
        if (g_dumpReady) {
            Serial.print("       out16:");
            for (int k = 0; k < 16; k++) Serial.printf(" %6d", g_dumpBuf[k]);
            Serial.print("\n");
            g_dumpReady = 0;   // re-arm snapshot in eltroProcessBlock
        }
        g_blockCount = 0;
        g_inPeak     = 0;
        g_outPeak    = 0;
    }
}
